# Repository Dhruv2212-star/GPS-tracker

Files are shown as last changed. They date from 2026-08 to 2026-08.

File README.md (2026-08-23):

Ai ussage- debugging firmware  
Project description- a small pocket sized instrument that uses GPS module paired with Xiao RP2040 module as the MCU to track your coordinates every min that you can put on websites like google maps or GPS visualizer, it uses a small Li-Po battery to save some space and also prevent and hazard related to fires from damage. it also has a charging USB-c port to charge the battery and charging and protection based on TP4056. there are 3 LEDs that provide data on GPS logging, data logging and power. there is also a push button to provide the user control for stopping, starting or making event loggs. 

------------------------------------------------------------------------------------------------------------------------------------------
# Firmware flashing 

**1. Install Arduino IDE**  
   Download and install the latest ver. from the official website (avoid microsoft store ver)  
**2. Install XIAO RP2040 board support.**  
Open Arduino IDE  
File->Prefrences  
Find Additional Boards Manager URLs.  
Add:  
https://github.com/earlephilhower/arduino-pico/releases/download/global/package_rp2040_index.json  
Click Ok  
Then-  
Tools->Board->Board manager  
search- Pico  
Install- Raspberry Pi Pico/RP2040/RP2350  
**3. Connect the XIAO**  
**IF Board is *NOT* detected:**  
    1. Hold the Boot button  
    2. connect the USB  
    3. Release BOOT  
    the computer should show RPI-RP2 when the Xiao enters Bootloader mode  
**4. Select the board**  
In Arduino IDE:  
Tools->Board->Raspberry Pi RP2040 Boards_>Seeed XIAO RP2040  
Then: Tools->Port  
Select the port corresponding to your Xiao  
**5. Install TinyGPSPlus**  
The firmware i made uses:  
#include <TinyGPSPlus.h>  
Go to:  
Sketch->Include->Manage liberaries  
Search:  
**TinyGPSPlus**  
**6. Open The firmware in arduino IDE**  
**8. First compile WITHOUT the PCB**  
**9. Upload to the XIAO**  
Click: Upload   
**10. Open Serial Monitor**  
Tools-> Serial monitor  
Set: 115200 baud  
You should be able to see the following-  
Initializing microSD...  
microSD OK  
GPS Tracker ready.  
Press SW1 to START/STOP logging.  
If the GPS is **not** Connected then you might see: Fix: NO | Satellites: NA | Logging: NO  
**11. Insert the microSD card**  
When the board starts Our firmware would start as following:  
Initializing microSD...  
microSD OK  
**12. Connect the GPS antenna**  
Fix: YES | Satellites: 8 | Logging: NO  
If this is what it shows then you are good to go  
now,  
No fix > D4 OFF  

Valid fix > D4 ON  
**14. Start logging**  
Press SW1.  
Our firmware will:  

Create a new file.  
Generate like:  
**TRACK00.CSV**  
Start logging.   
Turn D5 ON.  
Record one GPS position approximately every second  
The Display should show:  
Logging STARTED  
Then,  
GPS record written.  
GPS record written  
GPS record written.  
**15. Stop logging**  
If you press SW1 again, you'll see 'Logging STOPPED'  
Our firmware flushes & closes the Recording file before stopping, which is important for preventing an unfinished CSV file.  
**16. Check the SD card**  
You should find a file named- TRACK00.CSV  
you can open it with Excel (recommended)  

Here is an example of what it will contain: **Date,Time,Latitude,Longitude,Altitude_m,Speed_kmh,Satellites**  

------------------------------------------------------------------------------------------------------------------------------------------
# Lets get into the project details and the function of each block and the components present in them! 
 ## block 1  
   

 1. USB-c: (J1) for charging the battery or powering the device  
 2. F1- polyfuse: protects the board from excessive input current  
 3. D1- Protects the board from input voltage spikes  
 4. R1- CC1 pulldown   
 5. R2- CC2- pulldown  
## block 2


1. TP4056 (U1): main ic for charging the battery  
2. R3- sets the charging current for battery  
3. C1- stabalises the input current from the charger's side  
4. C2- stabalizes the battery input current of the charger  
5. D2- indicates battery is charging  
6. D3- indicates that the charging is complete  
7. R4- limits D2 current to prevent it from burnout  
8. R5- Limits D3 current to prevent it from burnout  
## Block 3 
 

1. AP2112K-3.3 (U2): converts battery voltage-> 3.3v  
2. C2- LDO input  
3. C3- filter 3.3v  
## Block 4 
 

1. Rp4020 module (u3)- the MCU for the project  
2. C5- decoupling capacitor for U3   
## Block 5
  

1. MAX-M10S (U4): the main GPS module that recives the satalite rays 
2. C6- decoupling for U4  
3. C7additional capacitor for filtering supply  
4. J3- antena  
## Block 6  
  

1. SD card (J4): the storage for the cordinates that the GPS module records  
2. C8: servers as the purpose of high frequency decoupling
3. C9: servers as the purpose of 3.3v supply filtering
## Block 7 
 

1. D4, indicates the GPS status  
2. D5 indicates the GPS data logging    
3. D6 Indicates board power
4. R6: protect D3 from overcurrent  
5. R7: protect D4 from overcurrent
6. R8: protect D5 from overcurrent
7. SW1: For User control  

png

# Final product 


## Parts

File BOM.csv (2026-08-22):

Reference | Qty | Value | DNP | Exclude from BOM | Exclude from Board | Footprint | Datasheet
C1,C2,C3,C4,C9 | 5 | 10 µF |  |  |  | Capacitor_SMD:C_0603_1608Metric
C5,C6,C8 | 3 | 100 nF |  |  |  | Capacitor_SMD:C_0603_1608Metric
C7 | 1 | 4.7 µF |  |  |  | Capacitor_SMD:C_0603_1608Metric
D1 | 1 | ESD5Zxx |  |  |  | Diode_SMD:D_SOD-523 | https://www.onsemi.com/pdf/datasheet/esd5z2.5t1-d.pdf
D2,D3,D4,D5,D6 | 5 | LED |  |  |  | LED_SMD:LED_0603_1608Metric
F1 | 1 | Polyfuse |  |  |  | Fuse:Fuse_1206_3216Metric
J1 | 1 | USB_C_Receptacle |  |  |  | Connector_USB:USB_C_Receptacle_GCT_USB4105-xx-A_16P_TopMnt_Horizontal | https://www.usb.org/sites/default/files/documents/usb_type-c.zip
J2 | 1 | Conn_01x02_Pin |  |  |  | Connector_JST:JST_PH_B2B-PH-K_1x02_P2.00mm_Vertical
J3 | 1 | Conn_Coaxial |  |  |  | Connector_Coaxial:U.FL_Hirose_U.FL-R-SMT-1_Vertical
J4 | 1 | Micro_SD_Card |  |  |  | Connector_Card:microSD_HC_Hirose_DM3AT-SF-PEJM5 | https://www.we-online.com/components/products/datasheet/693072010801.pdf
R1,R2 | 2 | R |  |  |  | Resistor_SMD:R_0603_1608Metric
R3 | 1 | 2 kΩ |  |  |  | Resistor_SMD:R_0603_1608Metric
R4,R5,R6,R7,R8 | 5 | 1 kΩ |  |  |  | Resistor_SMD:R_0603_1608Metric
SW1 | 1 | SW_Push |  |  |  | Button_Switch_SMD:SW_SPST_TL3305A
U1 | 1 | TP4056-42-ESOP8 |  |  |  | Package_SO:SOIC-8-1EP_3.9x4.9mm_P1.27mm_EP2.41x3.3mm_ThermalVias | https://www.lcsc.com/datasheet/lcsc_datasheet_2410121619_TOPPOWER-Nanjing-Extension-Microelectronics-TP4056-42-ESOP8_C16581.pdf
U2 | 1 | AP2112K-3.3 |  |  |  | Package_TO_SOT_SMD:SOT-23-5 | https://www.diodes.com/assets/Datasheets/AP2112.pdf
U3 | 1 | MOUDLE-SEEEDUINO-XIAO |  |  |  | my footprints:XIAO-Generic-Hybrid-14P-2.54-21X17.8MM
U4 | 1 | MAX-M10S |  |  |  | RF_GPS:ublox_MAX | https://content.u-blox.com/sites/default/files/MAX-M10S_DataSheet_UBX-20035208.pdf

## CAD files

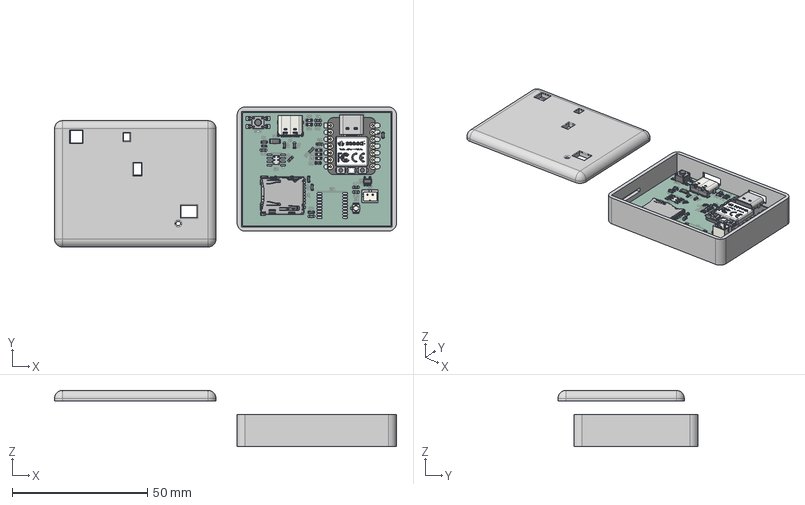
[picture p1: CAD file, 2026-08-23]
CAD/Assembly.step
126.6 x 51.9 x 20.9 mm
type-c v2
smd_button v3
DOUT
DIN
VSS
VDD
smd_button v3(Mirror)
top case
Bottom case
LED_0603_1608Metric x 5
C_0603_1608Metric x 9
SW_SPST_TL3305A
R_0603_1608Metric x 8
SOT-23-5
Fuse_1206_3216Metric
JST_B2B_PH_K
microSD_HC_Hirose_DM3AT-SF-PEJM5
USB_C_Receptacle_16P_TopMnt_Horizontal_GCT_USB4105-xx-A
D_SOD_523
U.FL_Hirose_U.FL-R-SMT-1_Vertical
GPS traacker_copper
GPS traacker_pad
GPS traacker_via
GPS traacker_silkscreen
GPS traacker_soldermask
GPS traacker_soldermask (1)
GPS traacker_PCB

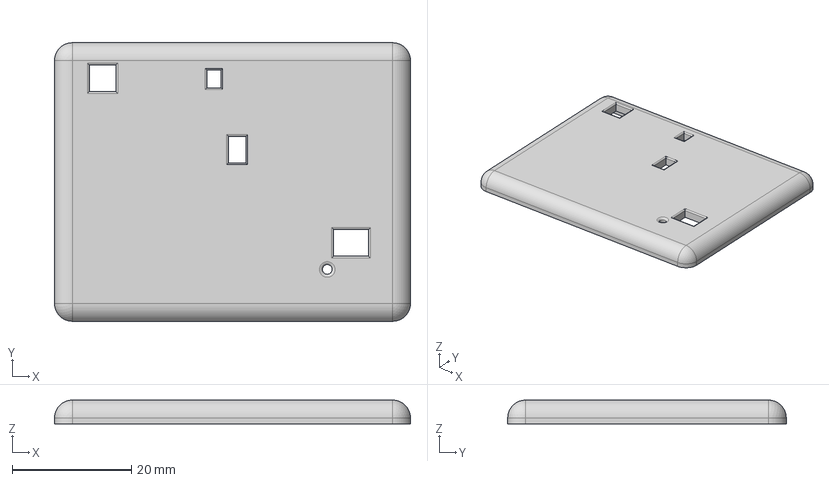
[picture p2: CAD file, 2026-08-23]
CAD/Top Case_.step
59.8 x 46.8 x 4.00 mm

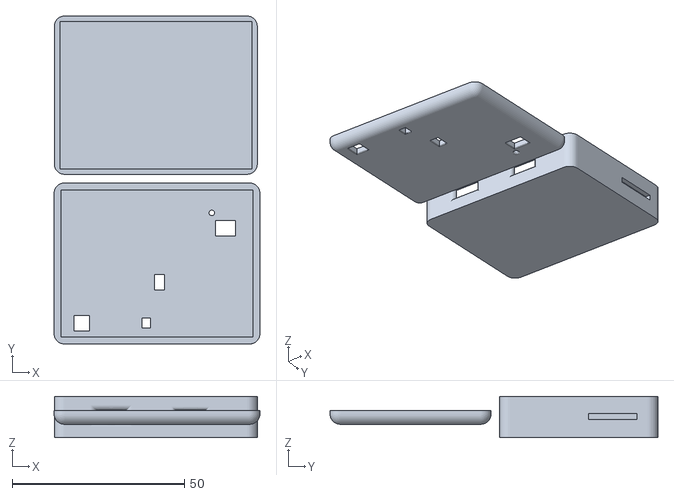
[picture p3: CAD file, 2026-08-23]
Production/Case_.stl
59.8 x 95.3 x 12.0

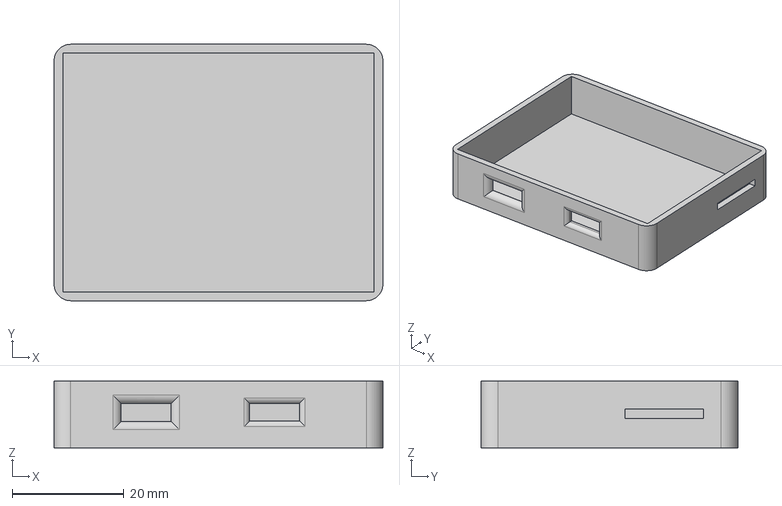
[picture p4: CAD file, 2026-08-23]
CAD/Bottom case.step
59.0 x 46.0 x 12.0 mm

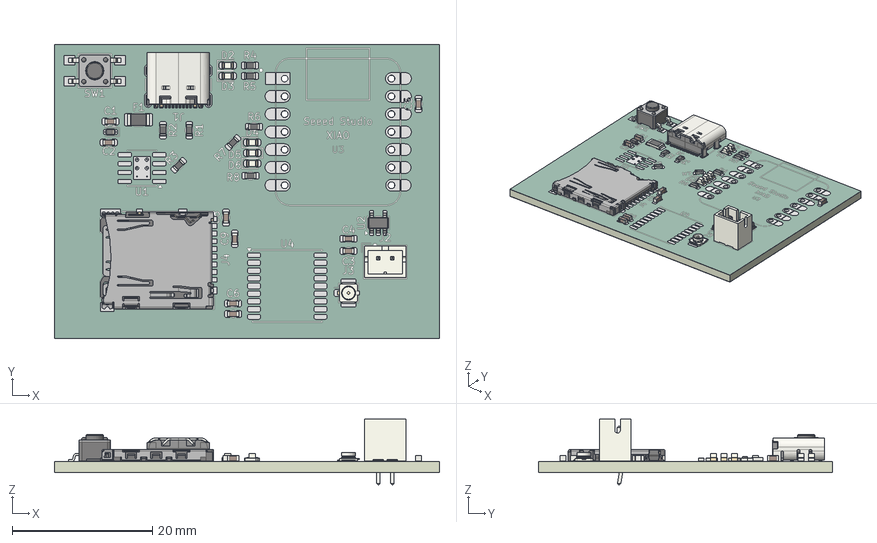
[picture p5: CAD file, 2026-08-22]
CAD/PCB_3D_Model.step
55.0 x 42.0 x 9.40 mm
LED_0603_1608Metric x 5
C_0603_1608Metric x 9
SW_SPST_TL3305A
R_0603_1608Metric x 8
SOT-23-5
Fuse_1206_3216Metric
JST_B2B_PH_K
microSD_HC_Hirose_DM3AT-SF-PEJM5
USB_C_Receptacle_16P_TopMnt_Horizontal_GCT_USB4105-xx-A
D_SOD_523
U.FL_Hirose_U.FL-R-SMT-1_Vertical
GPS traacker_copper
GPS traacker_pad
GPS traacker_via
GPS traacker_silkscreen
GPS traacker_soldermask x 2
GPS traacker_PCB

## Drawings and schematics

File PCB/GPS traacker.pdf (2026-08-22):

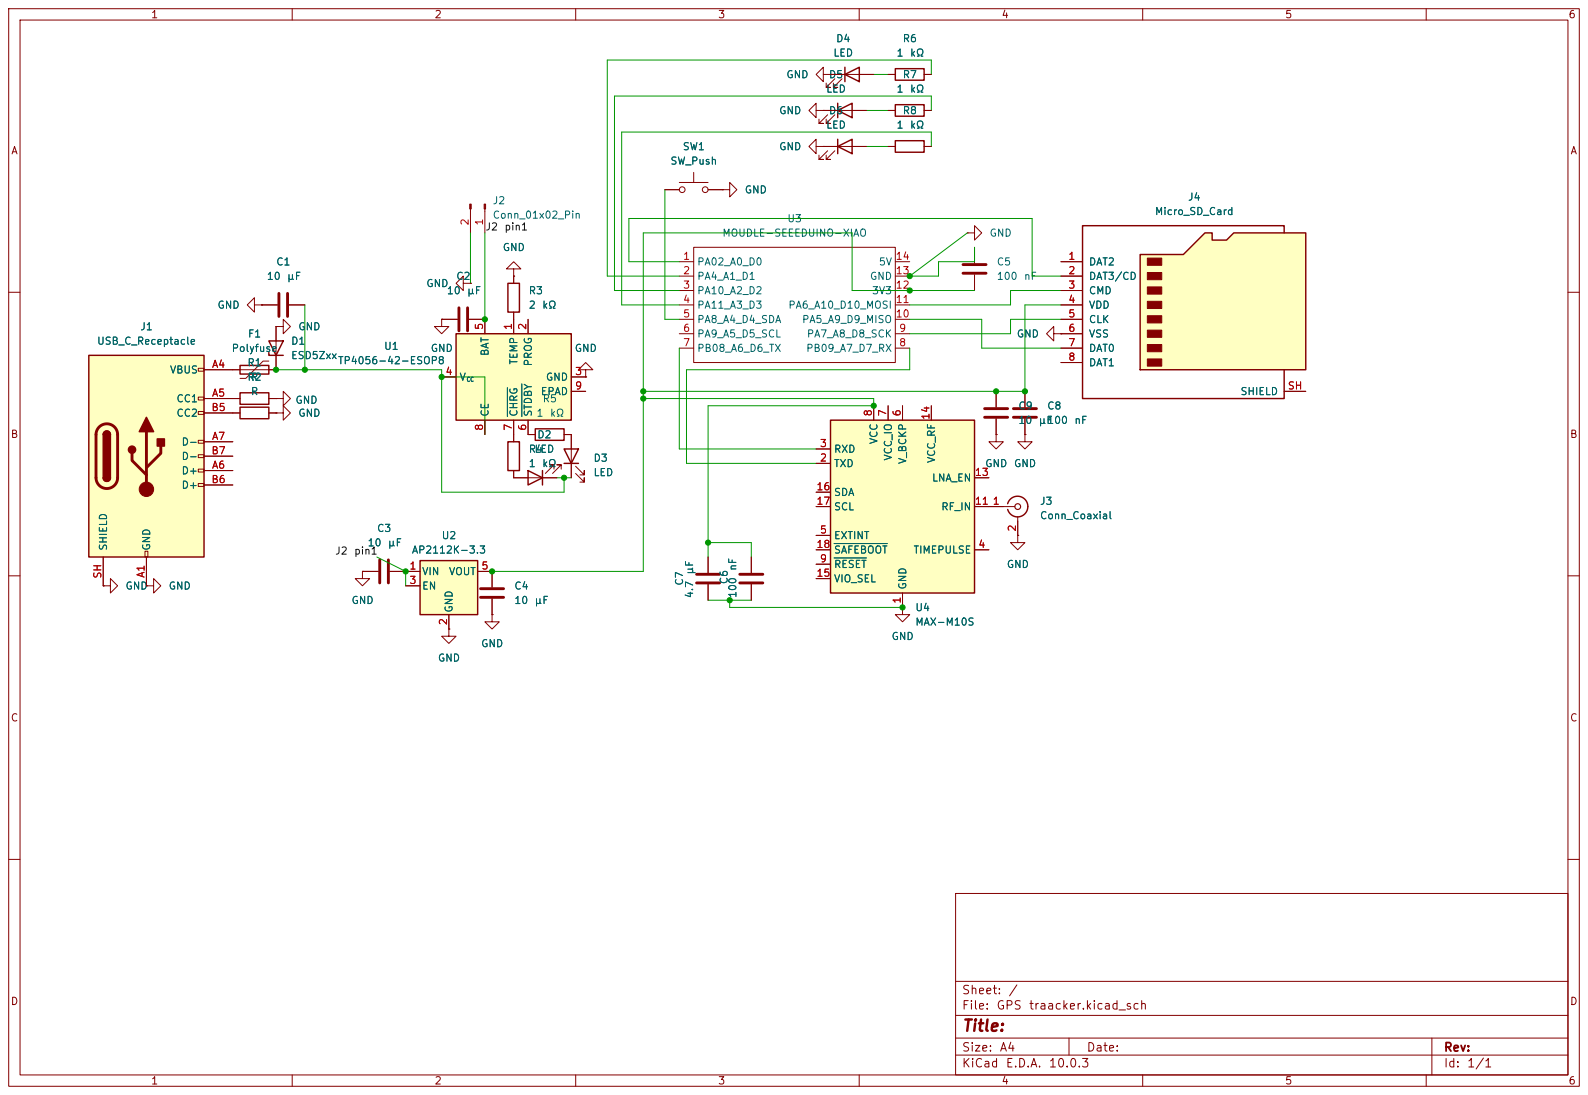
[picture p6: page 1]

Size: A4 | Rev:
KiCad E.D.A. 10.0.3 | Id: 1/1

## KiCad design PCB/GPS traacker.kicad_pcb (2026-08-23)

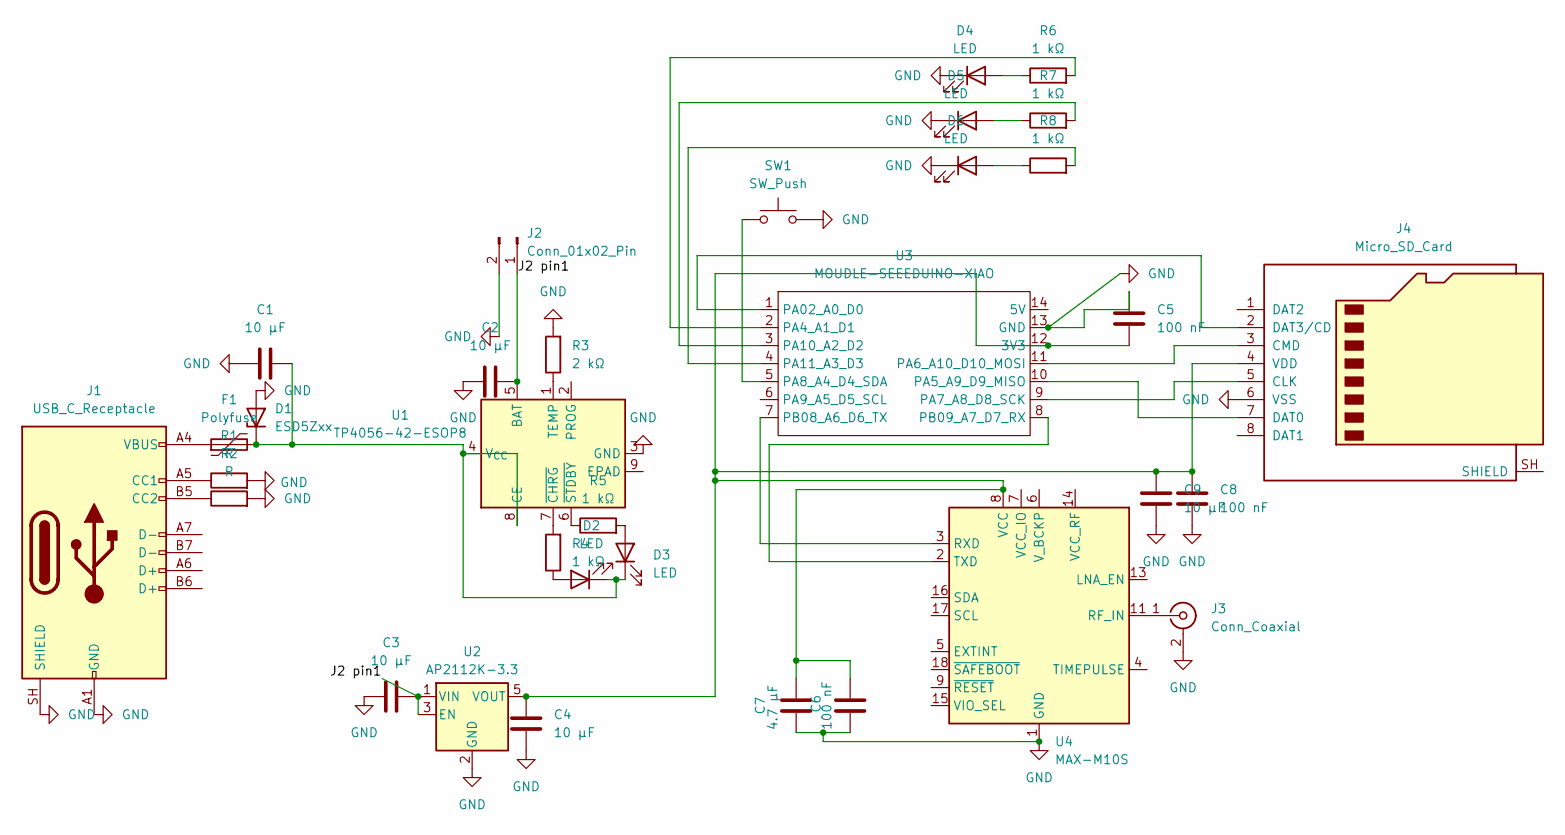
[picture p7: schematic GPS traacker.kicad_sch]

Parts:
C1, C2, C3, C4, C9: 10 µF; C_0603_1608Metric
C5, C6, C8: 100 nF; C_0603_1608Metric
C7: 4.7 µF; C_0603_1608Metric
D1: ESD5Zxx; D_SOD-523
D2, D3, D4, D5, D6: LED; LED_0603_1608Metric
F1: Polyfuse; Fuse_1206_3216Metric
J1: USB_C_Receptacle; USB_C_Receptacle_GCT_USB4105-xx-A_16P_TopMnt_Horizontal
J2: Conn_01x02_Pin; JST_PH_B2B-PH-K_1x02_P2.00mm_Vertical
J3: Conn_Coaxial; U.FL_Hirose_U.FL-R-SMT-1_Vertical
J4: Micro_SD_Card; microSD_HC_Hirose_DM3AT-SF-PEJM5
R1, R2: R; R_0603_1608Metric
R3: 2 kΩ; R_0603_1608Metric
R4, R5, R6, R7, R8: 1 kΩ; R_0603_1608Metric
SW1: SW_Push; SW_SPST_TL3305A
U1: TP4056-42-ESOP8; SOIC-8-1EP_3.9x4.9mm_P1.27mm_EP2.41x3.3mm_ThermalVias
U2: AP2112K-3.3; SOT-23-5
U3: MOUDLE-SEEEDUINO-XIAO; XIAO-Generic-Hybrid-14P-2.54-21X17.8MM
U4: MAX-M10S; ublox_MAX

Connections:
/J2 pin1: C2.2, C3.2, J2.1, U1.5 (BAT), U2.1 (VIN), U2.3 (EN)
GND: C1.2, C2.1, C3.1, C4.2, C5.2, C6.1, C7.1, C8.2, C9.2, D1.2 (A), D4.1 (K), D5.1 (K), D6.1 (K), J1.A1 (GND), J1.A12 (GND), J1.B1 (GND), J1.B12 (GND), J1.SH (SHIELD), J2.2, J3.2 (Ext), J4.6 (VSS), R1.2, R2.2, R3.2, SW1.2, U1.3 (GND), U2.2 (GND), U3.13 (GND), U4.1 (GND), U4.10 (GND), U4.12 (GND)
unnamed: C1.1, D1.1 (K), D2.1 (K), D3.1 (K), F1.2, U1.4 (V_{CC}), U1.8 (CE)
unnamed: D2.2 (A), R4.1
unnamed: D3.2 (A), R5.2
unnamed: D4.2 (A), R6.1
unnamed: D5.2 (A), R7.1
unnamed: D6.2 (A), R8.1
unnamed: F1.1, J1.A4 (VBUS), J1.A9 (VBUS), J1.B4 (VBUS), J1.B9 (VBUS)
unnamed: J1.A5 (CC1), R1.1
unnamed: J1.B5 (CC2), R2.1
unnamed: J3.1 (In), U4.11 (RF_IN)
unnamed: J4.5 (CLK), U3.9 (PA7_A8_D8_SCK)
unnamed: J4.3 (CMD), U3.11 (PA6_A10_D10_MOSI)
unnamed: J4.7 (DAT0), U3.10 (PA5_A9_D9_MISO)
unnamed: J4.2 (DAT3/CD), U3.1 (PA02_A0_D0)
unnamed: C4.1, C5.1, C6.2, C7.2, C8.1, C9.1, J4.4 (VDD), U2.5 (VOUT), U3.12 (3V3), U4.8 (VCC)
unnamed: R3.1, U1.1 (TEMP)
unnamed: R4.2, U1.7 (~CHRG)
unnamed: R5.1, U1.6 (~STDBY)
unnamed: R6.2, U3.2 (PA4_A1_D1)
unnamed: SW1.1, U3.5 (PA8_A4_D4_SDA)
unnamed: R7.2, U3.3 (PA10_A2_D2)
unnamed: R8.2, U3.4 (PA11_A3_D3)
unnamed: U3.7 (PB08_A6_D6_TX), U4.3 (RXD)
unnamed: U3.8 (PB09_A7_D7_RX), U4.2 (TXD)

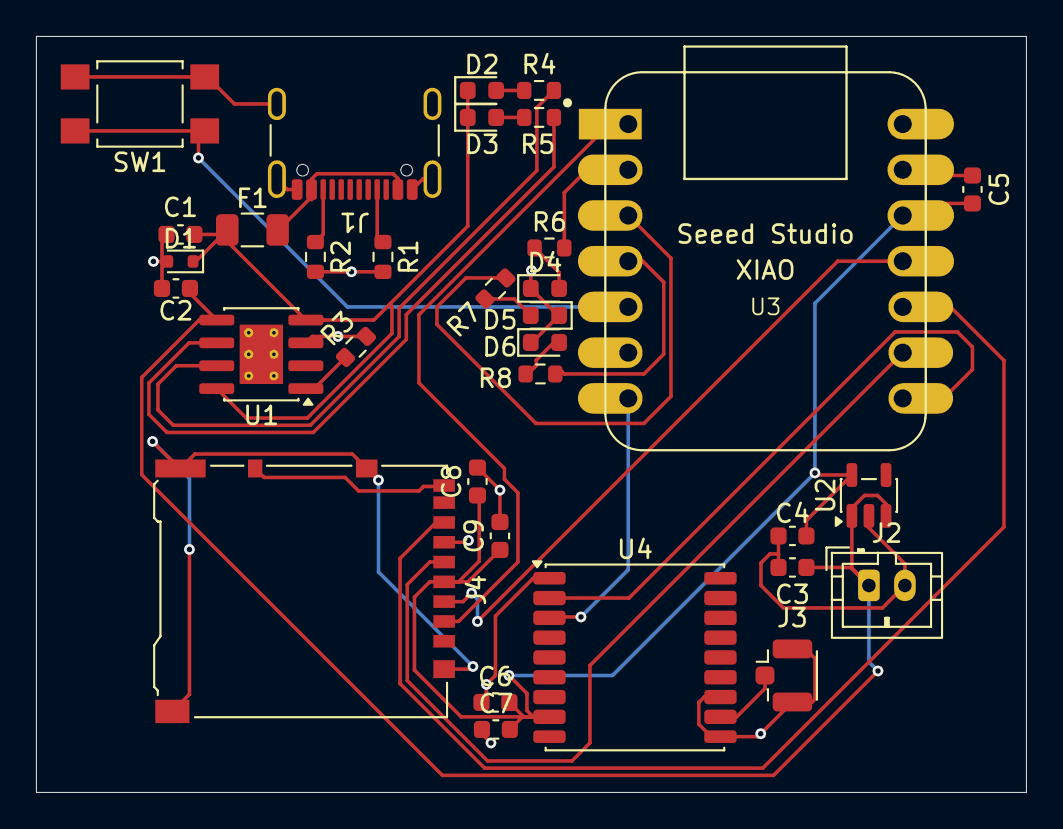
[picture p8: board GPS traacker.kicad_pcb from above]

Board: 2 copper layers, 55.0 x 42.0 mm, 33 parts (0 on the bottom side), 26 nets.

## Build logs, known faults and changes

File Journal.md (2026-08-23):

# Block 1 (45 mins) 
  

https://lapse.hackclub.com/timelapse/AD61pH7Mq9Ni  

# block 2 (1 hr)
https://lapse.hackclub.com/timelapse/f4P3DcXp9zT1  


# block 3 (28 mins)
https://lapse.hackclub.com/timelapse/ansFyVnUM9Qe  
 

# block 4 (23 mins)
https://lapse.hackclub.com/timelapse/CesDBkL3ewvQ  
 

# Block 5 (46 mins) 
https://lapse.hackclub.com/timelapse/hbAZfL0Ajnua  
  

# Block 6 (1hr)
https://lapse.hackclub.com/timelapse/3PsR25CJdTkE  
  

# schematic revision (54 mins)
https://lapse.hackclub.com/timelapse/aqsbU9o7Lmui

# Block 7 (14 mins)
https://lapse.hackclub.com/timelapse/1QvW8RoiY3GW  
 

# Block 7 schematic rebuilding and remaking the PCB board (1 hr 40mins)
https://lapse.hackclub.com/timelapse/WcefxnoK25GE  
Kicad crashed and i had to redo the schematic work and ENTIRE PCB routing once again   
 


# Assembly with casings for the PCB (2hr 7 mins)
https://lapse.hackclub.com/timelapse/lmnxHDu2uIR4  


# Firmware Help  (29mins)
https://lapse.hackclub.com/timelapse/8cMFgWjOZsth  
searched through the code and made the firmware help section in Readme file.

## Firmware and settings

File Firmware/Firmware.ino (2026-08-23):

#include <Arduino.h>
#include <TinyGPSPlus.h>
#include <SPI.h>
#include <SD.h>

// GPS TRACKER - Seeed XIAO RP2040
// Pin assignments match our PCB design.

// LEDs:
// D4 LED -> XIAO A1 / D1 / GPIO27
// D5 LED -> XIAO A2 / D2 / GPIO28
// D6 LED -> XIAO A3 / D3 / GPIO29
// D4 and D5 LEDs are ACTIVE-LOW.
// D6 is the hardware power LED and needs no GPIO control.
//
// Button:
// SW1 -> XIAO A4 / D4 / GPIO6 -> GND
//
// GPS:
// XIAO D6/TX -> GPS RX
// XIAO D7/RX <- GPS TX
//
// microSD SPI:
// XIAO D0  -> CS
// XIAO D8  -> SCK
// XIAO D9  <- MISO
// XIAO D10 -> MOSI

const uint8_t LED_GPS     = D1;
const uint8_t LED_LOGGING = D2;
const uint8_t BUTTON_PIN  = D4;

const uint8_t GPS_TX_PIN  = D6;
const uint8_t GPS_RX_PIN  = D7;

const uint8_t SD_CS_PIN   = D0;
const uint8_t SD_SCK_PIN  = D8;
const uint8_t SD_MISO_PIN = D9;
const uint8_t SD_MOSI_PIN = D10;

const uint32_t GPS_BAUD = 9600;
const uint32_t LOG_INTERVAL_MS = 1000;

TinyGPSPlus gps;
File logFile;

bool sdOK = false;
bool logging = false;
uint32_t lastLogTime = 0;
bool lastButtonState = HIGH;
uint32_t lastButtonChange = 0;
char logFilename[13];

void gpsLED(bool on) {
  digitalWrite(LED_GPS, on ? LOW : HIGH);
}

void loggingLED(bool on) {
  digitalWrite(LED_LOGGING, on ? LOW : HIGH);
}

bool createLogFile() {
  for (int i = 0; i < 100; i++) {
    snprintf(logFilename, sizeof(logFilename), "TRACK%02d.CSV", i);

    if (!SD.exists(logFilename)) {
      logFile = SD.open(logFilename, FILE_WRITE);

      if (!logFile) {
        return false;
      }

      logFile.println(
        "Date,Time,Latitude,Longitude,Altitude_m,Speed_kmh,Satellites"
      );
      logFile.flush();

      Serial.print("Logging to: ");
      Serial.println(logFilename);
      return true;
    }
  }

  return false;
}

void startLogging() {
  if (!sdOK || logging) {
    return;
  }

  if (!createLogFile()) {
    Serial.println("ERROR: Could not create log file.");
    return;
  }

  logging = true;
  lastLogTime = millis();
  loggingLED(true);
  Serial.println("Logging STARTED");
}

void stopLogging() {
  if (!logging) {
    return;
  }

  if (logFile) {
    logFile.flush();
    logFile.close();
  }

  logging = false;
  loggingLED(false);
  Serial.println("Logging STOPPED");
}

void writeGPSRecord() {
  if (!logging || !logFile) {
    return;
  }

  if (!gps.location.isValid()) {
    Serial.println("No valid GPS fix - record skipped.");
    return;
  }

  // Date
  if (gps.date.isValid()) {
    if (gps.date.month() < 10) logFile.print('0');
    logFile.print(gps.date.month());
    logFile.print('/');
    if (gps.date.day() < 10) logFile.print('0');
    logFile.print(gps.date.day());
    logFile.print('/');
    logFile.print(gps.date.year());
  } else {
    logFile.print("NO_DATE");
  }

  logFile.print(',');

  // UTC time
  if (gps.time.isValid()) {
    if (gps.time.hour() < 10) logFile.print('0');
    logFile.print(gps.time.hour());
    logFile.print(':');
    if (gps.time.minute() < 10) logFile.print('0');
    logFile.print(gps.time.minute());
    logFile.print(':');
    if (gps.time.second() < 10) logFile.print('0');
    logFile.print(gps.time.second());
  } else {
    logFile.print("NO_TIME");
  }

  logFile.print(',');
  logFile.print(gps.location.lat(), 6);
  logFile.print(',');
  logFile.print(gps.location.lng(), 6);
  logFile.print(',');

  if (gps.altitude.isValid()) {
    logFile.print(gps.altitude.meters(), 2);
  } else {
    logFile.print("NA");
  }

  logFile.print(',');

  if (gps.speed.isValid()) {
    logFile.print(gps.speed.kmph(), 2);
  } else {
    logFile.print("NA");
  }

  logFile.print(',');

  if (gps.satellites.isValid()) {
    logFile.println(gps.satellites.value());
  } else {
    logFile.println("NA");
  }

  logFile.flush();
  Serial.println("GPS record written.");
}

void handleButton() {
  bool currentState = digitalRead(BUTTON_PIN);

  if (currentState != lastButtonState) {
    lastButtonChange = millis();
    lastButtonState = currentState;
  }

  if ((millis() - lastButtonChange) > 40) {
    static bool handledPress = false;

    if (currentState == LOW && !handledPress) {
      handledPress = true;

      if (logging) {
        stopLogging();
      } else {
        startLogging();
      }
    }

    if (currentState == HIGH) {
      handledPress = false;
    }
  }
}

void setup() {
  Serial.begin(115200);
  delay(500);

  pinMode(LED_GPS, OUTPUT);
  pinMode(LED_LOGGING, OUTPUT);
  gpsLED(false);
  loggingLED(false);

  pinMode(BUTTON_PIN, INPUT_PULLUP);

  // GPS UART
  Serial1.setTX(GPS_TX_PIN);
  Serial1.setRX(GPS_RX_PIN);
  Serial1.begin(GPS_BAUD);

  // microSD SPI
  SPI.setRX(SD_MISO_PIN);
  SPI.setTX(SD_MOSI_PIN);
  SPI.setSCK(SD_SCK_PIN);
  SPI.setCS(SD_CS_PIN);
  SPI.begin();

  Serial.println("Initializing microSD...");
  sdOK = SD.begin(SD_CS_PIN);

  if (sdOK) {
    Serial.println("microSD OK");
  } else {
    Serial.println("ERROR: microSD initialization failed.");
  }

  Serial.println("GPS Tracker ready.");
  Serial.println("Press SW1 to START/STOP logging.");
}

void loop() {
  // Feed GPS NMEA data to TinyGPSPlus.
  while (Serial1.available()) {
    gps.encode(Serial1.read());
  }

  gpsLED(gps.location.isValid());

  handleButton();

  if (logging && (millis() - lastLogTime >= LOG_INTERVAL_MS)) {
    lastLogTime += LOG_INTERVAL_MS;
    writeGPSRecord();
  }

  static uint32_t lastDebug = 0;

  if (millis() - lastDebug >= 5000) {
    lastDebug = millis();

    Serial.print("Fix: ");
    Serial.print(gps.location.isValid() ? "YES" : "NO");

    Serial.print(" | Satellites: ");
    if (gps.satellites.isValid()) {
      Serial.print(gps.satellites.value());
    } else {
      Serial.print("NA");
    }

    Serial.print(" | Logging: ");
    Serial.println(logging ? "YES" : "NO");
  }
}
